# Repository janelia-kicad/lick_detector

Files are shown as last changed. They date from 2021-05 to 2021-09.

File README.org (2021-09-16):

# Created 2021-05-13 Thu 11:52
#+OPTIONS: title:nil author:nil email:nil toc:t |:t ^:nil
* Repository Information

- Name :: lick_detector
- Version :: 1.0
- License :: Open-Source Hardware
- URL :: https://github.com/janelia-kicad/lick_detector
- Author :: Peter Polidoro
- Email :: peter@polidoro.io

** Description

This board was designed to detect mouse licks using an accelerometer. The
board needs to be small and light weight and mounted to a lickport tube that
allows some small amount of motion.

* Images

* Schematic

[[file:./schematic/lick_detector.pdf][./schematic/lick_detector.pdf]]

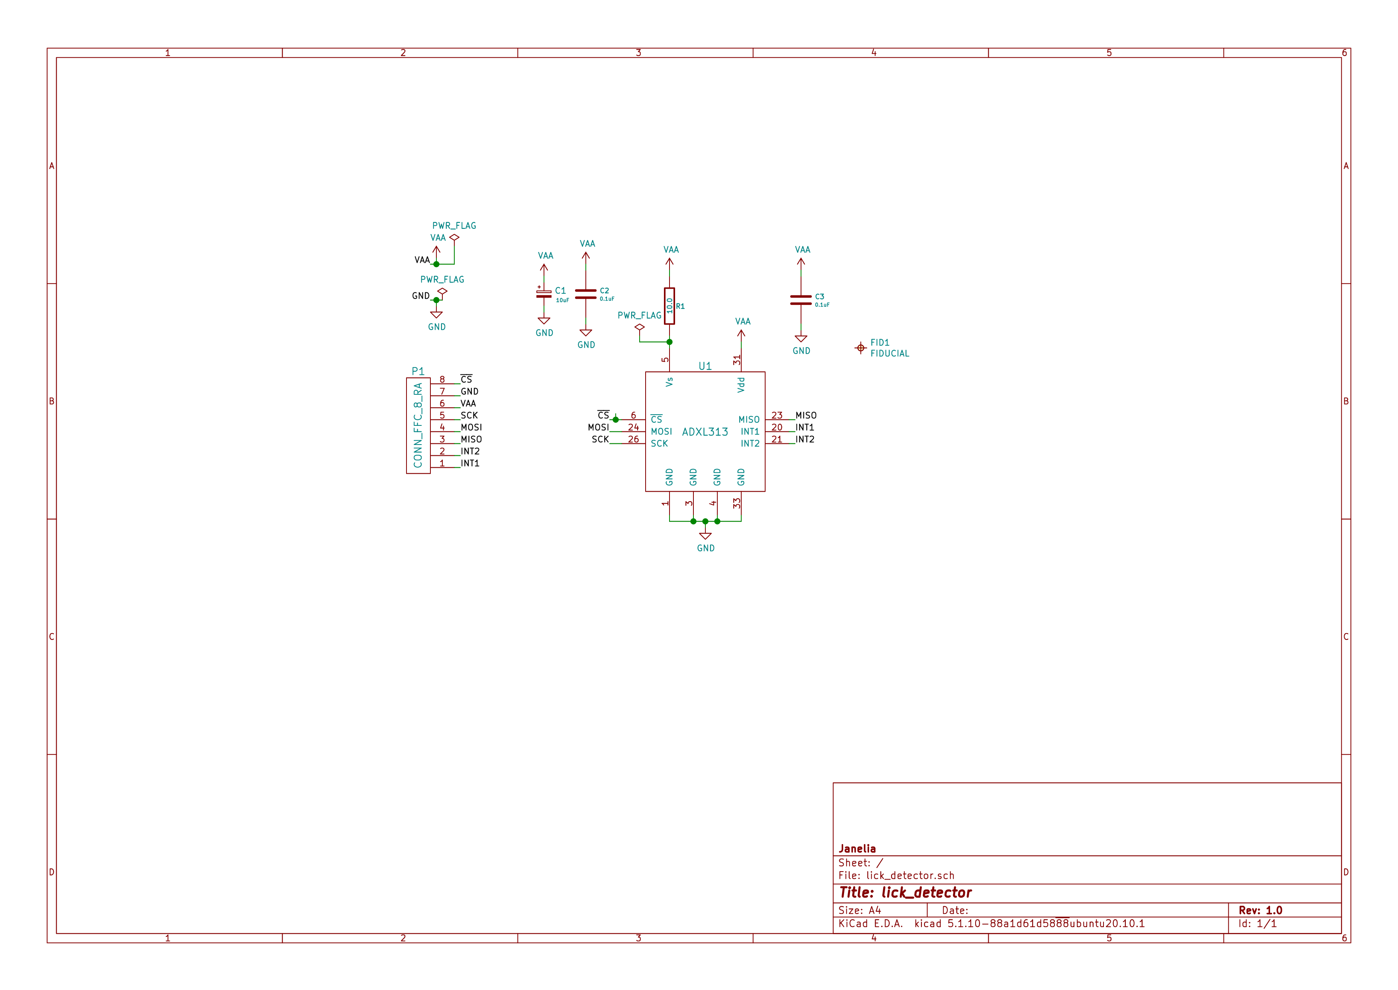
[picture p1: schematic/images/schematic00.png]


* Gerbers

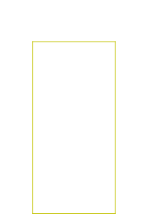
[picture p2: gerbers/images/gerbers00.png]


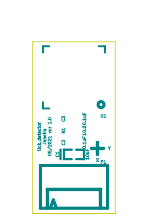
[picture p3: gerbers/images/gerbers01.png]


* Bill of Materials

** PCB Parts

| Item | Reference(s) | Quantity | Manufacturer       | Manufacturer Part Number | Vendor   | Vendor Part Number    | Description                  | Package |
|------+--------------+----------+--------------------+--------------------------+----------+-----------------------+------------------------------+---------|
|    1 | C1           |        1 | AVX Corporation    | TLCK106M006QTA           | Digi-Key | 478-5343-1-ND         | CAP TANT 10UF 20% 6.3V       |    0402 |
|    2 | C2 C3        |        2 | TDK Corporation    | C0603X5R1E104K030BB      | Digi-Key | 445-13671-1-ND        | CAP CER 0.1UF 25V X5R        |    0201 |
|    3 | P1           |        1 | Molex              | 5034800800               | Digi-Key | WM1388CT-ND           | CONN FFC FPC 8POS 0.50MM R/A |         |
|    4 | R1           |        1 | Yageo              | RC0201JR-0710RL          | Digi-Key | 311-10NCT-ND          | RES SMD 10 OHM 5% 1/20W      |    0201 |
|    5 | U1           |        1 | Analog Devices Inc | ADXL313WACPZ-RL7         | Digi-Key | ADXL313WACPZ-RL7CT-ND | ACCEL 0.5-4G I2C/SPI 32LFCSP |         |
|      | FID1         |        1 |                    |                          |          |                       |                              |         |

** Supplemental Parts

| Item | Quantity | Manufacturer | Manufacturer Part Number | Vendor   | Vendor Part Number | Description                  |
|------+----------+--------------+--------------------------+----------+--------------------+------------------------------|
|    1 |        1 | Molex        |               0150200073 | Digi-Key | 0150200073-ND      | CABLE FFC 8POS 0.50MM 1.18in |
|    2 |        1 | Molex        |               0150200075 | Digi-Key | WM11389-ND         | CABLE FFC 8POS 0.50MM 2in    |
|    3 |        1 | Molex        |               0150200077 | Digi-Key | 0150200077-ND      | CABLE FFC 8POS 0.50MM 3in    |
|    4 |        1 | Molex        |               0150200079 | Digi-Key | WM11395-ND         | CABLE FFC 8POS 0.50MM 4in    |
|    5 |        1 | Molex        |               0150200081 | Digi-Key | 0150200081-ND      | CABLE FFC 8POS 0.50MM 5in    |
|    6 |        1 | Molex        |               0150200083 | Digi-Key | WM6662-ND          | CABLE FFC 8POS 0.50MM 6in    |
|    7 |        1 | Molex        |               0150200087 | Digi-Key | WM11411-ND         | CABLE FFC 8POS 0.50MM 8in    |
|    8 |        1 | Molex        |               0150200093 | Digi-Key | WM25022-ND         | CABLE FFC 8POS 0.50MM 12in   |
#+TBLFM: $1=@#-1

** Vendor Parts Lists

[[file:./bom/Digi-Key_parts.csv][./bom/Digi-Key_parts.csv]]

* Supplemental Documentation

** Assembly Instructions

- Solder surface mount components onto the pcb.

* Manufacturing Archive

Send manufacturing zip file to your favorite PCB manufacturer for fabrication.

[[file:./manufacturing/lick_detector_v1.0.zip][./manufacturing/lick_detector_v1.0.zip]]

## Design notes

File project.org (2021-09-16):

* Header                                                           :noexport:

  #+MACRO: name lick_detector
  #+MACRO: version 1.0
  #+MACRO: license Open-Source Hardware
  #+MACRO: url https://github.com/janelia-kicad/lick_detector
  #+AUTHOR: Peter Polidoro
  #+EMAIL: peter@polidoro.io

* Description

  This board was designed to detect mouse licks using an accelerometer. The
  board needs to be small and light weight and mounted to a lickport tube that
  allows some small amount of motion.

* Assembly Instructions

  - Solder surface mount components onto the pcb.

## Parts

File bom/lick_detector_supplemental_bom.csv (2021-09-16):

Item | Quantity | Manufacturer | Manufacturer Part Number | Vendor | Vendor Part Number | Description
1 | 25 | Molex | 0150200073 | Digi-Key | 0150200073-ND | CABLE FFC 8POS 0.50MM 1.18in
2 | 25 | Molex | 0150200075 | Digi-Key | WM11389-ND | CABLE FFC 8POS 0.50MM 2in
3 | 25 | Molex | 0150200077 | Digi-Key | 0150200077-ND | CABLE FFC 8POS 0.50MM 3in
4 | 25 | Molex | 0150200079 | Digi-Key | WM11395-ND | CABLE FFC 8POS 0.50MM 4in
5 | 25 | Molex | 0150200081 | Digi-Key | 0150200081-ND | CABLE FFC 8POS 0.50MM 5in
6 | 25 | Molex | 0150200083 | Digi-Key | WM6662-ND | CABLE FFC 8POS 0.50MM 6in
7 | 25 | Molex | 0150200087 | Digi-Key | WM11411-ND | CABLE FFC 8POS 0.50MM 8in
8 | 25 | Molex | 0150200093 | Digi-Key | WM25022-ND | CABLE FFC 8POS 0.50MM 12in

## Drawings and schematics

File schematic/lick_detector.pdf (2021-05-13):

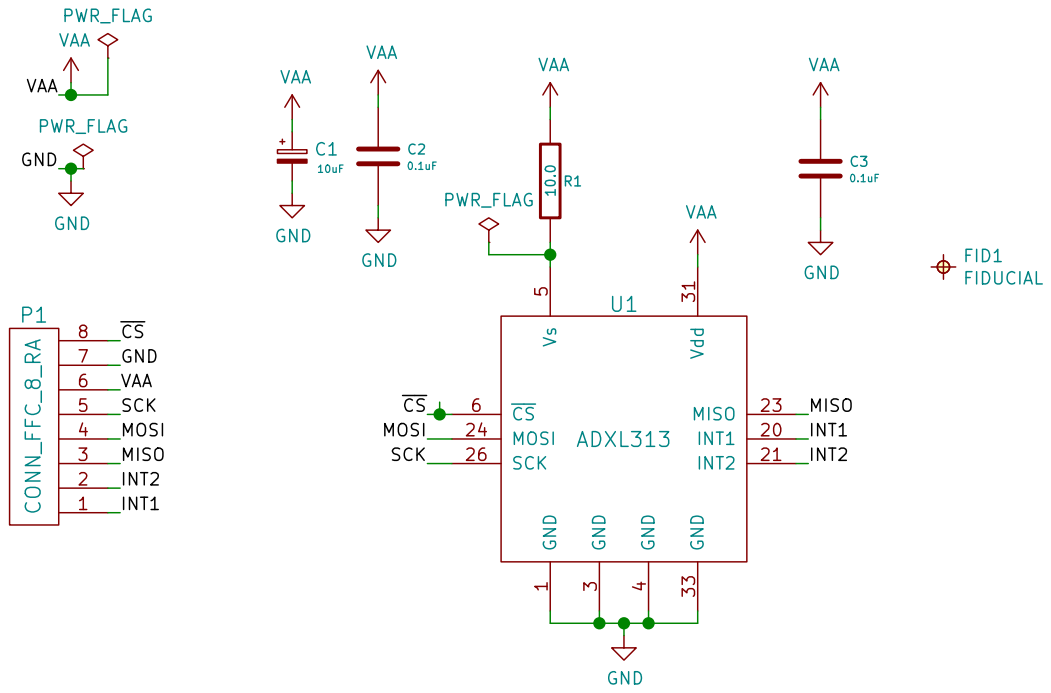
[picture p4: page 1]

File: lick_detector.sch Sheet: / Janelia

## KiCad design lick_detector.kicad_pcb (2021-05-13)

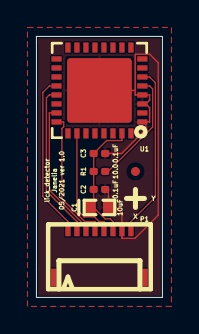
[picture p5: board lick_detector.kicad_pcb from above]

Board: 2 copper layers, 7.0 x 14.5 mm, 7 parts (0 on the bottom side), 9 nets.

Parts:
C1: 10uF; SM0402_POL
C2, C3: 0.1uF; SM0201
FID1: FIDUCIAL
P1: CONN_FFC_8_RA; Molex_FFC_1x8_P0.5mm_RA
R1: 10.0; SM0201
U1: ADXL313; LFCSP-32-1EP_5x5mm_P0.5mm_EP3.6x3.6mm

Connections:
/INT1: P1.1, U1.20
/INT2: P1.2, U1.21
/MISO: P1.3, U1.23
/MOSI: P1.4, U1.24
/SCK: P1.5, U1.26
/~CS: P1.8, U1.6
GND: C1.2, C2.2, C3.2, P1.7, U1.1, U1.3, U1.4, U1.33
unnamed: R1.2, U1.5
VAA: C1.1, C2.1, C3.1, P1.6, R1.1, U1.31

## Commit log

2021-04-30 Add ADXL313
    [lick_detector.kicad_pcb, lick_detector.sch]
2021-05-01 Add Pico-Clasp 8-pin
2021-05-03 Add Pico-Clasp component
    [lick_detector.sch]
2021-05-03 Add connector to schematic
    [lick_detector.sch]
2021-05-04 Add capacitors and receptacle
    [lick_detector.dsn, lick_detector.kicad_pcb, lick_detector.sch]
2021-05-04 Add 10.0_0402
    [lick_detector.sch]
2021-05-04 Add 10k
    [lick_detector.sch]
2021-05-05 Add BUFFER_TRI_STATE and BUFFER_2_ELEMENT
    [lick_detector.kicad_pcb, lick_detector.sch]
2021-05-06 Switch to flex cable
    [lick_detector.kicad_pcb, lick_detector.sch]
2021-05-07 Migrate toward 0201
    [lick_detector.kicad_pcb, lick_detector.sch]
2021-05-10 Rearrange pcb footprints
    [lick_detector.kicad_pcb, lick_detector.sch]
2021-05-10 Layout experimentation
    [lick_detector.dsn, lick_detector.kicad_pcb, lick_detector.sch]
2021-05-10 Auto routed layout
    [lick_detector.dsn, lick_detector.kicad_pcb, lick_detector.sch]
2021-05-12 Remove pin receptacle
    [lick_detector.kicad_pcb, lick_detector.sch]
2021-05-12 Rectangular outline
    [lick_detector.dsn, lick_detector.kicad_pcb, lick_detector.sch]
2021-05-12 Add all flex cable sizes to supplemental_bom
2021-05-13 Export supplementals
    [lick_detector-B_Cu.gbl, lick_detector-B_Mask.gbs, lick_detector-B_Paste.gbp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]
2021-05-13 Generate documentation
    [Digi-Key_parts.csv, bom.csv]
2021-09-16 Update email address
    [lick_detector_supplemental_bom.csv]
2021-09-21 Remove ignored files
    [lick_detector.dsn]
